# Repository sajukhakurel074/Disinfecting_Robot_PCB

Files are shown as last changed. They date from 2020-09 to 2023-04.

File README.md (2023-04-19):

# Disinfecting_Robot
Main circuit board design for disinfecting Robot Project.

This project was funded by Nepal Academy of Science and Technology (NAST) during the Covid-19 pandemic. The main aim of this project was to use a remotely comtrolled robot that would spary the disinfecting solution in the infected areas.

# Features of the board
1. Simple 4 wheel drive
2. Bluetooth controlled functions
3. Relay switched Water Pump
4. 2-D axis spraying arm 
  - Servo for y-axis
  - Stepper for x-axis
5. Proximity sensor at the edges to avoid collision

# Final Board After Assmebly 
119986601_873003923236254_8257088440001949787_n
119949055_959485604533560_8313327878339021860_n

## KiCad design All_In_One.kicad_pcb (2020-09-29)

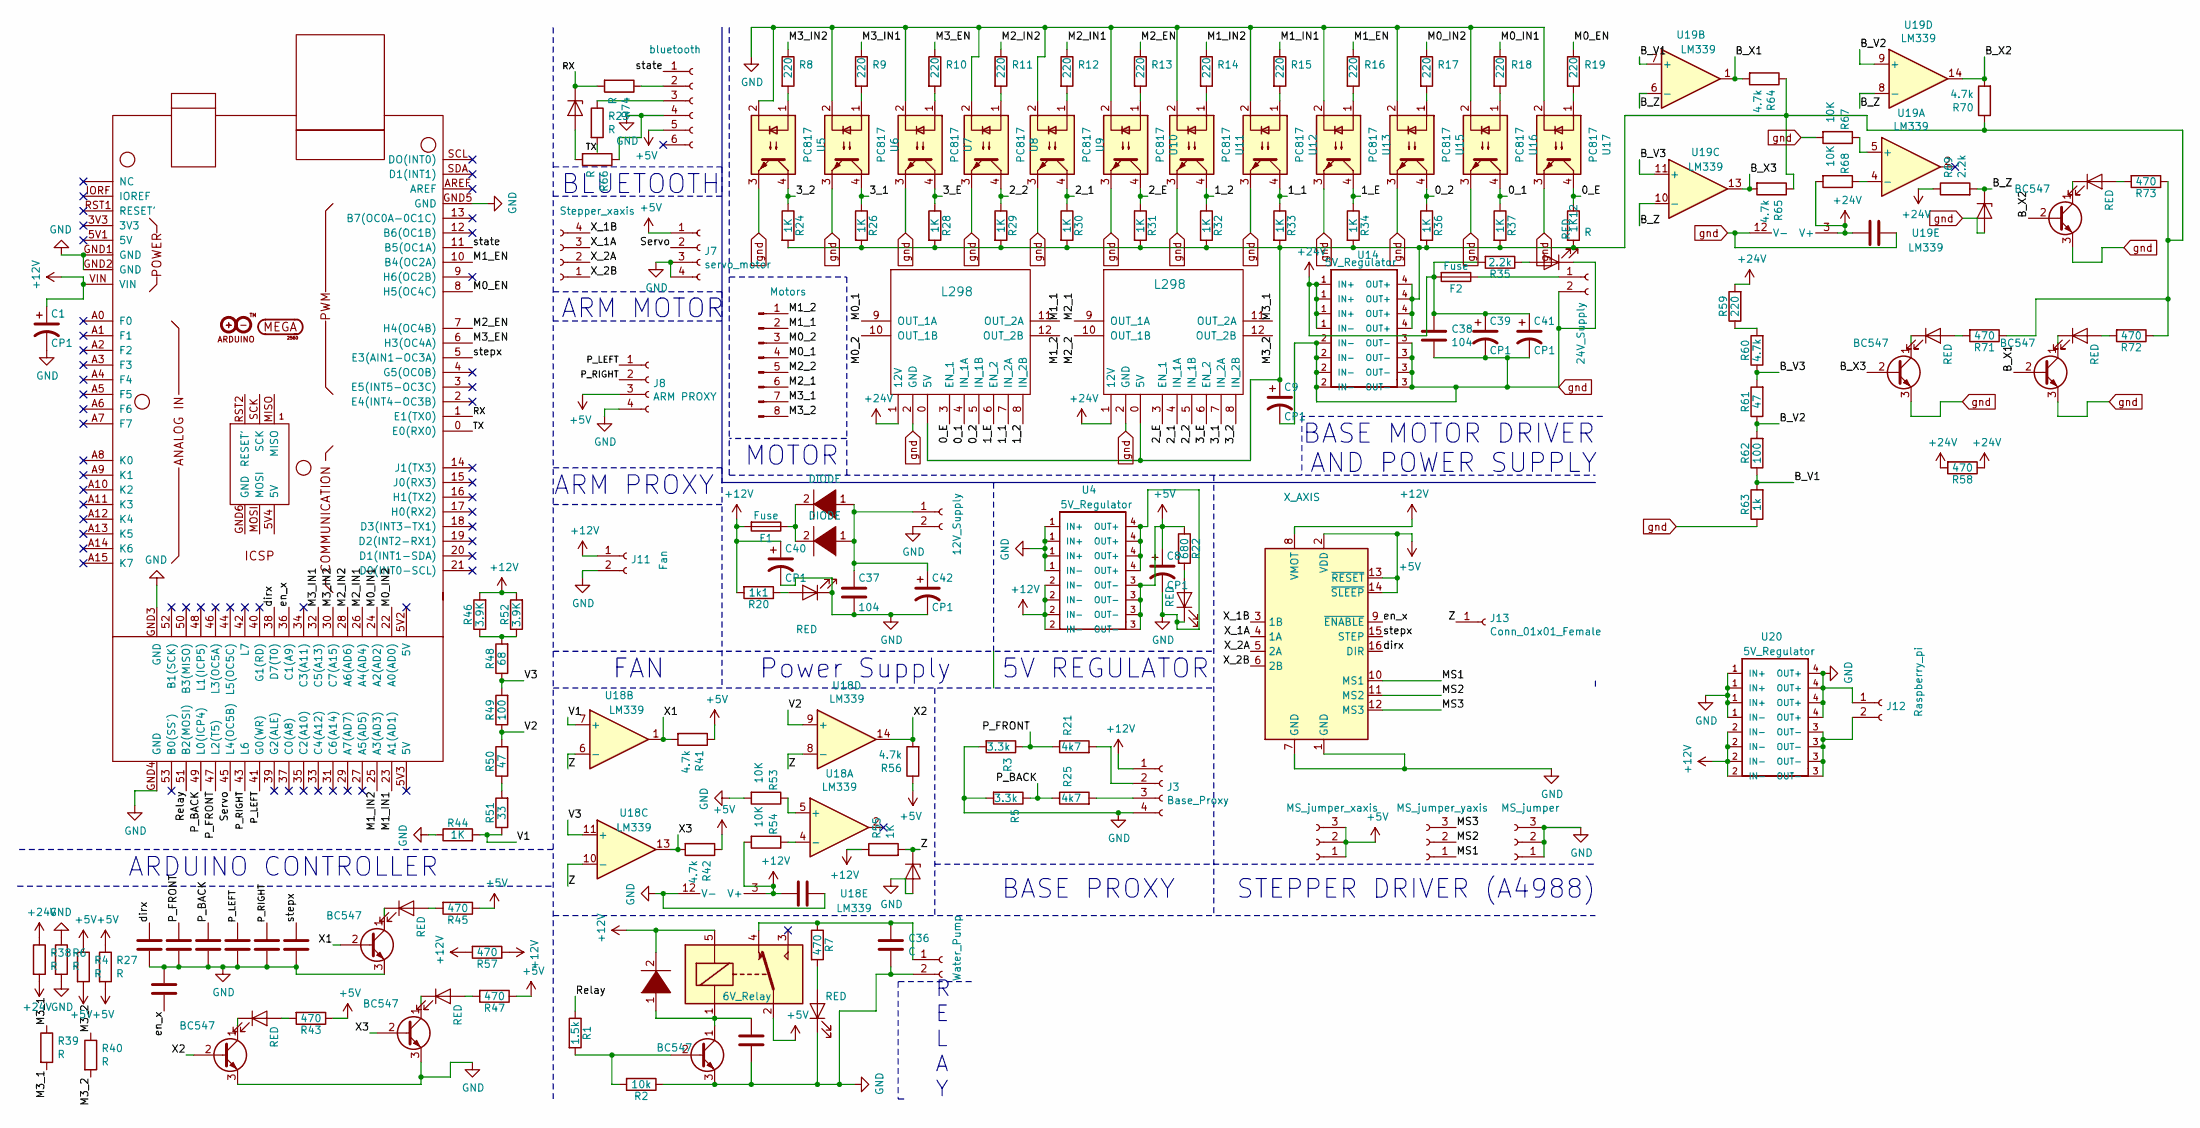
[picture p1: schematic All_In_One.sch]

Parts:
1K12: R; Resistor_small
A1: X_AXIS; A4998
C1, C8, C9, C40, C41: CP1; Capacitor_1000uF
C2, C3, C4, C5, C6, C7, C13, C25, C27, C33, C36: C; Capacitor_Disc_Small
C37, C38: 104; Capacitor_Disc_Small
C39, C42: CP1; Capacitor_10uF
D1, D3, D10: DIODE; Diode_Medium
D2, D4, D5, D6, D8, D9, D11, D13, D15, D16: RED; LED_D3.0mm
D7, D12, D14: D_Zener; D_T-1_P5.08mm_Horizontal
F1, F2: Fuse; Fuse_Holder
J1: MS_jumper_xaxis; PinHeader_1x03_P2.54mm_Vertical
J2: MS_jumper_yaxis; PinHeader_1x03_P2.54mm_Vertical
J3: Base_Proxy; New_conn_1x4
J4: Water_Pump; New_conn_1x2
J5: MS_jumper; PinHeader_1x03_P2.54mm_Vertical
J6: Stepper_xaxis; New_conn_1x4
J7: servo_motor; New_conn_1x4
J8: ARM PROXY; New_conn_1x4
J9: bluetooth
J10: Motors; New_conn_1x8
J11: Fan; New_conn_1x2
J12: Raspberry_pi; New_conn_1x2
J13: Conn_01x01_Female; PinHeader_1x01_P2.00mm_Vertical
Q1, Q2, Q3, Q4, Q5, Q6, Q7: BC547
R1: 1.5k; Resistor_small
R2: 10k; Resistor_small
R3, R5: 3.3k; Resistor_small
R4, R6, R23, R27, R38, R39, R40, R66, R74: R; Resistor_small
R7, R43, R45, R47, R57, R58, R71, R72, R73: 470; Resistor_small
R8, R9, R10, R11, R12, R13, R14, R15, R16, R17, R18, R19, R59: 220; Resistor_small
R20: 1k1; Resistor_small
R21, R25: 4k7; Resistor_small
R22: 680; Resistor_small
R24, R26, R28, R29, R30, R31, R32, R33, R34, R36, R37, R44, R55: 1K; Resistor_small
R35, R69: 2.2k; Resistor_small
R41, R42, R56, R60, R64, R65, R70: 4.7k; Resistor_small
R46, R52: 3.9K; Resistor_small
R48: 68; Resistor_small
R49, R62: 100; Resistor_small
R50, R61: 47; Resistor_small
R51: 33; Resistor_small
R53, R54, R67, R68: 10K; Resistor_small
R63: 1k; Resistor_small
Rly1: 6V_Relay; Relay_6V
U1: Prashant_library_Arduino_Mega2560_Shield; Arduino_Mega2560_Shield
U2, U3: L298; saju_____L298
U4, U20: 5V_Regulator; Buck_5A
U5, U6, U7, U8, U9, U10, U11, U12, U13, U15, U16, U17: PC817; DIP-4_W7.62mm
U14: 5V_Regulator; Buck_Regulator
U18, U19: LM339; DIP-14_W7.62mm_LongPads
d1: 12V_Supply; Solar_Connector
d2: 24V_Supply; Solar_Connector

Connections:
+5V: A1.2 (VDD), A1.13 (~RESET), A1.14 (~SLEEP), C8.1, J1.1, J1.2, J1.3, J7.1, J8.3, J9.5, R4.1, R4.2, R22.1, R27.1, R27.2, R41.1, R42.1, R43.1, R45.1, R47.1, R56.1, Rly1.2, U4.3 (OUT-); also elsewhere on the board
+12V: A1.8 (VMOT), C1.1, C4.2, C40.1, D1.2 (A), F1.2, J3.1, J11.1, R20.2, R46.2, R52.2, R54.2, R55.1, R57.1, R57.2, Rly1.5, U1.VIN, U4.2 (IN-), U18.3 (V+), U20.2 (IN-); also elsewhere on the board
+24V: C6.2, C38.1, C39.1, C41.1, F2.2, R35.2, R38.1, R38.2, R58.1, R58.2, R59.2, R68.2, R69.1, U2.1 (12V), U3.1 (12V), U14.1 (IN+), U19.3 (V+)
/0_1: R37.1, U2.4 (IN_1A), U16.4
/0_2: R36.1, U2.5 (IN_1B), U15.4
/0_E: 1K12.1, U2.3 (EN_1), U17.4
/1_1: R33.1, U2.7 (IN_2A), U12.4
/1_2: R32.1, U2.8 (IN_2B), U11.4
/1_E: R34.1, U2.6 (EN_2), U13.4
/2_1: R30.1, U3.4 (IN_1A), U9.4
/2_2: R29.1, U3.5 (IN_1B), U8.4
/2_E: R31.1, U3.3 (EN_1), U10.4
/3_1: R26.1, U3.7 (IN_2A), U6.4
/3_2: R24.1, U3.8 (IN_2B), U5.4
/3_E: R28.1, U3.6 (EN_2), U7.4
/B_V1: R62.1, R63.2, U19.7 (+)
/B_V2: R61.1, R62.2, U19.9 (+)
/B_V3: R60.1, R61.2, U19.11 (+)
/B_X1: Q6.2 (B), R64.2, U19.1
/B_X2: Q7.2 (B), R70.2, U19.14; also elsewhere on the board
/B_X3: Q5.2 (B), R65.2, U19.13
/B_Z: D14.1 (K), R69.2, U19.6 (-), U19.8 (-), U19.10 (-)
/M0_1: J10.4, U2.9 (OUT_1A)
/M0_2: J10.3, U2.10 (OUT_1B)
/M0_EN: R19.1, U1.8 (H5(OC4C))
/M0_IN1: R18.1, U1.24 (A2(AD2))
/M0_IN2: R17.1, U1.22 (A0(AD0))
/M1_1: J10.2, U2.11 (OUT_2A)
/M1_2: J10.1, U2.12 (OUT_2B)
/M1_EN: R16.1, U1.10 (B4(OC2A))
/M1_IN1: R15.1, U1.23 (A1(AD1))
/M1_IN2: R14.1, U1.25 (A3(AD3))
/M2_1: J10.6, U3.9 (OUT_1A)
/M2_2: J10.5, U3.10 (OUT_1B)
/M2_EN: R13.1, U1.7 (H4(OC4B))
/M2_IN1: R12.1, U1.26 (A4(AD4))
/M2_IN2: R11.1, U1.28 (A6(AD6))
/M3_1: J10.7, R39.1, R39.2, U3.11 (OUT_2A)
/M3_2: J10.8, R40.1, R40.2, U3.12 (OUT_2B)
/M3_EN: R10.1, U1.6 (H3(OC4A))
/M3_IN1: R9.1, U1.32 (C5(A13))
/M3_IN2: R8.1, U1.30 (C7(A15))
/MS1: A1.10 (MS1), J2.1; also elsewhere on the board
/MS2: A1.11 (MS2), J2.2; also elsewhere on the board
/MS3: A1.12 (MS3), J2.3; also elsewhere on the board
/P_BACK: C5.1, R5.1, R25.1, U1.49 (L0(ICP4))
/P_FRONT: C2.1, R3.1, R21.1, U1.47 (L2(T5))
/P_LEFT: C25.1, J8.1, U1.41 (G0(WR))
/P_RIGHT: C27.1, J8.2, U1.43 (L6)
/RX: D7.1 (K), R74.2, U1.1 (E1(TX0))
/Relay: R1.1, U1.51 (B2(MOSI))
/Servo: J7.2, U1.45 (L4(OC5B))
/TX: R23.2, U1.0 (E0(RX0))
/V1: R44.2, R51.1, U18.7 (+)
/V2: R49.1, R50.2, U18.9 (+)
/V3: R48.1, R49.2, U18.11 (+)
/X1: Q3.2 (B), R41.2, U18.1
/X2: Q2.2 (B), R56.2, U18.14
/X3: Q4.2 (B), R42.2, U18.13
/X_1A: A1.4 (1A), J6.3
/X_1B: A1.3 (1B), J6.4
/X_2A: A1.5 (2A), J6.2
/X_2B: A1.6 (2B), J6.1
/Z: D12.1 (K), J13.1, R55.2, U18.6 (-), U18.8 (-), U18.10 (-); also elsewhere on the board
/dirx: A1.16 (DIR), C13.1, U1.38 (D7(T0))
/en_x: A1.9 (~ENABLE), C3.1, U1.36 (C1(A9))
/state: J9.1, U1.11 (B5(OC1A))
/stepx: A1.15 (STEP), C33.1, U1.5 (E3(AIN1-OC3A))
GND: A1.1 (GND), A1.7 (GND), C1.2, C2.2, C3.2, C4.1, C5.2, C7.2, C8.2, C13.2, C25.2, C27.2, C33.2, C36.2, C37.2, C40.2, C42.2, D2.1 (K), D9.1 (K), D11.1 (K), D12.2 (A), J3.4, J4.2, J5.1, J5.2, J5.3, J7.3, J7.4, J8.4, J9.4, J11.2, J12.1, Q1.3 (E), Q2.3 (E), Q3.3 (E), Q4.3 (E), R2.1, R3.2, R5.2, R6.1, R6.2, R44.1, R53.2, R66.1, U1.GND1 (GND), U1.GND2 (GND), U1.GND3 (GND), U1.GND4 (GND), U1.GND5 (GND), U4.1 (IN+), U4.4 (OUT+), U5.2, U6.2, U7.2, U8.2, U9.2, U10.2, U11.2, U12.2, U13.2, U15.2, U16.2, U17.2, U18.12 (V-), U20.1 (IN+), U20.4 (OUT+), d1.2; also elsewhere on the board
unnamed 69: 1K12.2, C9.1, R24.2, R26.2, R28.2, R29.2, R30.2, R31.2, R32.2, R33.2, R34.2, R36.2, R37.2, R64.1, R65.1, R70.1, R71.1, R72.1, R73.1, U2.0 (5V), U3.0 (5V), U14.4 (OUT+); also elsewhere on the board
unnamed: C7.1, D1.1 (K), Q1.1 (C), Rly1.1
unnamed: C36.1, J4.1, R7.1, Rly1.4
unnamed 72: C37.1, C42.1, D3.1 (K), D10.1 (K), d1.1; also elsewhere on the board
unnamed: D2.2 (A), R7.2
unnamed: D4.1 (K), Q2.1 (C)
unnamed: D4.2 (A), R43.2
unnamed: D5.1 (K), Q3.1 (C)
unnamed: D5.2 (A), R45.2
unnamed: D6.1 (K), Q4.1 (C)
unnamed: D6.2 (A), R47.2
unnamed: D7.2 (A), R66.2
unnamed: D8.2 (A), R35.1
unnamed: D9.2 (A), R20.1
unnamed: D3.2 (A), D10.2 (A), F1.1
unnamed: D11.2 (A), R22.2
unnamed: D13.1 (K), Q5.1 (C)
unnamed: D13.2 (A), R71.2
unnamed: D15.1 (K), Q6.1 (C)
unnamed: D15.2 (A), R72.2
unnamed: D16.1 (K), Q7.1 (C)
unnamed: D16.2 (A), R73.2
unnamed: F2.1, d2.1
unnamed: J3.2, R21.2
unnamed: J3.3, R25.2
unnamed: J9.2, R74.1
unnamed: J9.3, R23.1
unnamed: J12.2, U20.3 (OUT-)
unnamed: Q1.2 (B), R1.2, R2.2
unnamed: R8.2, U5.1
unnamed: R9.2, U6.1
unnamed: R10.2, U7.1
unnamed: R11.2, U8.1
unnamed: R12.2, U9.1
unnamed: R13.2, U10.1
unnamed: R14.2, U11.1
unnamed: R15.2, U12.1
unnamed: R16.2, U13.1
unnamed: R17.2, U15.1
unnamed: R18.2, U16.1
unnamed: R19.2, U17.1
unnamed: R46.1, R48.2, R52.1
unnamed: R50.1, R51.2
unnamed: R53.1, U18.5 (+)
unnamed: R54.1, U18.4 (-)
unnamed: R59.1, R60.2
unnamed: R67.1, U19.5 (+)
unnamed: R68.1, U19.4 (-)
gnd: C6.1, C9.2, C38.2, C39.2, C41.2, D8.1 (K), D14.2 (A), Q5.3 (E), Q6.3 (E), Q7.3 (E), R63.1, R67.2, U2.2 (GND), U3.2 (GND), U5.3, U6.3, U7.3, U8.3, U9.3, U10.3, U11.3, U12.3, U13.3, U14.2 (IN-), U14.3 (OUT-), U15.3, U16.3, U17.3, U19.12 (V-), d2.2

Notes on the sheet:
ARM PROXY
5V REGULATOR
ARDUINO CONTROLLER
MOTOR
BASE PROXY
STEPPER DRIVER (A4988)
BASE MOTOR DRIVER
AND POWER SUPPLY
Power Supply
BLUETOOTH
R E L A Y
FAN
ARM MOTOR

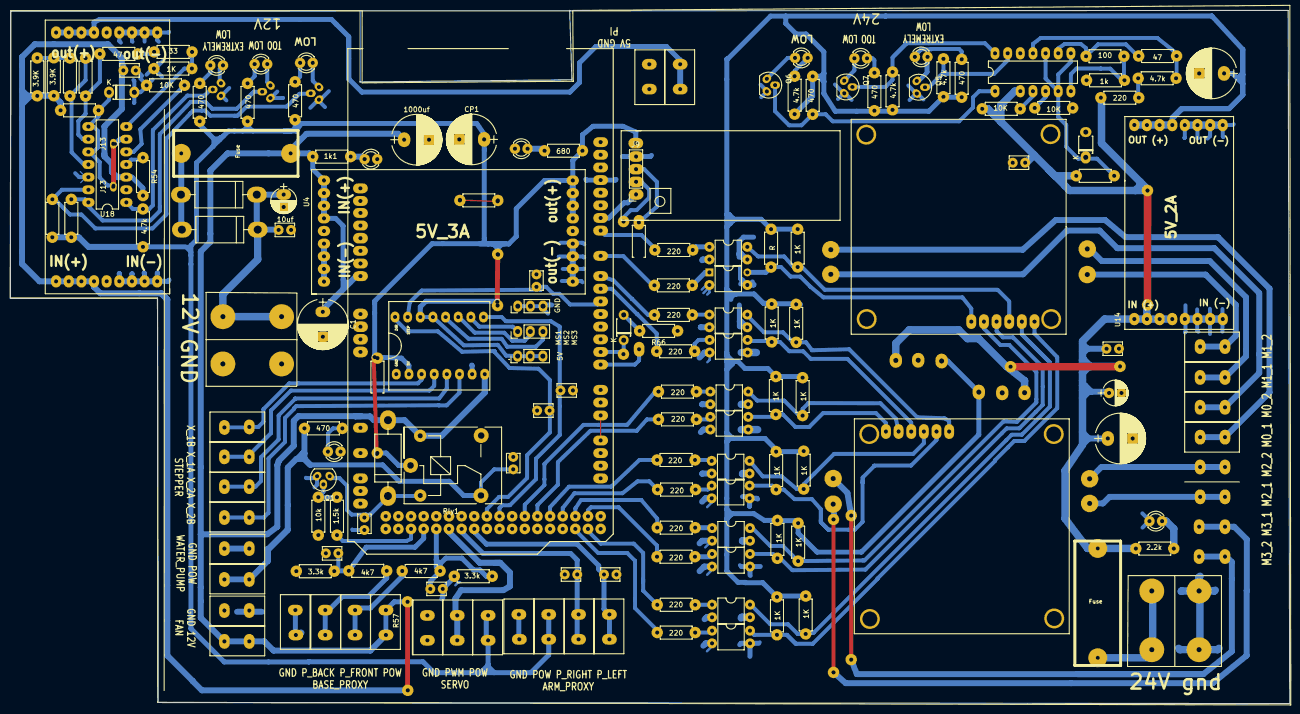
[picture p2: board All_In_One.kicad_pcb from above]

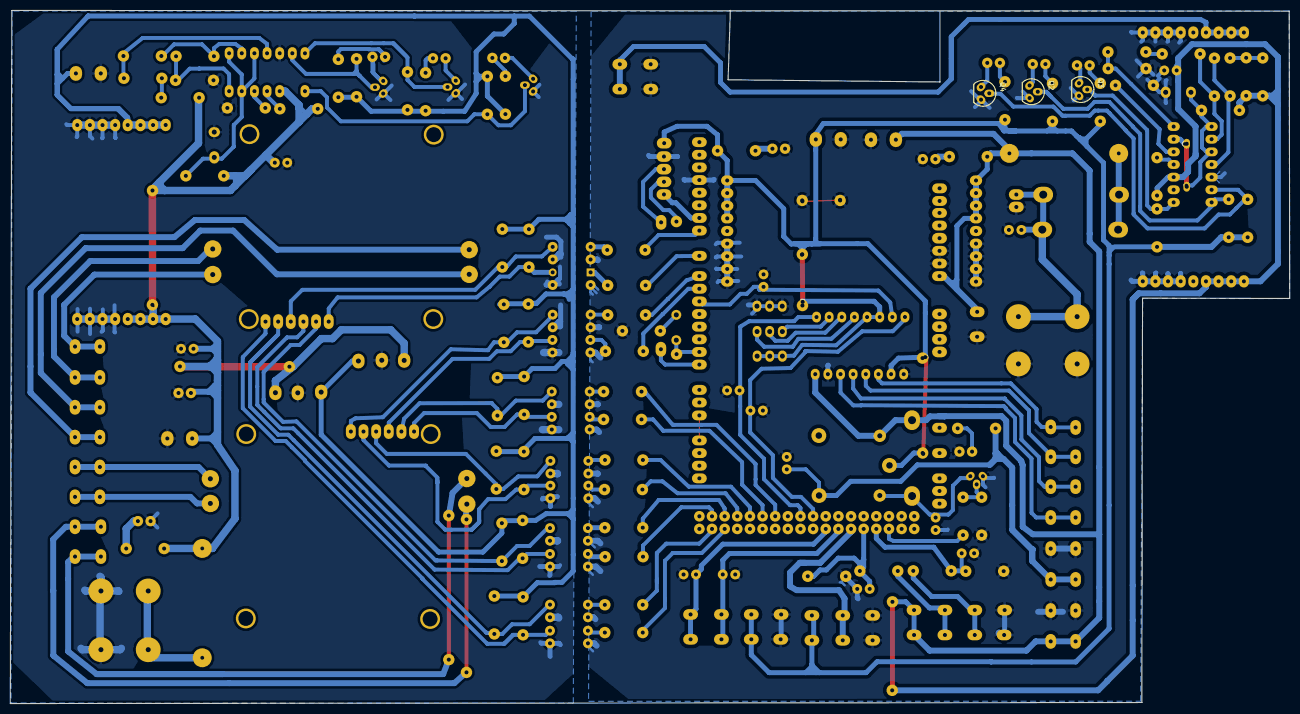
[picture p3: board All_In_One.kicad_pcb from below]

Board: 2 copper layers, 257.1 x 139.3 mm, 158 parts (3 on the bottom side), 118 nets.

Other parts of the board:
5V: MS_jumper_xaxis; PinHeader_1x03_P2.54mm_Vertical
10uf: CP1; Capacitor_10uF
1000uf: CP1; Capacitor_1000uF
GND: MS_jumper; PinHeader_1x03_P2.54mm_Vertical
J13#2: Conn_01x01_Female; PinHeader_1x01_P2.00mm_Vertical
MS1: MS_jumper_yaxis; PinHeader_1x03_P2.54mm_Vertical
eR70: 4.7k; Resistor_small

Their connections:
+5V: 5V.1, 5V.2, 5V.3; also elsewhere on the board
+12V: 1000uf.1; also elsewhere on the board
/B_X2: eR70.2; also elsewhere on the board
/MS1: MS1.1; also elsewhere on the board
/MS2: MS1.2; also elsewhere on the board
/MS3: MS1.3; also elsewhere on the board
/Z: J13#2.1; also elsewhere on the board
GND: 10uf.2, 1000uf.2, GND.1, GND.2, GND.3; also elsewhere on the board
unnamed 69: eR70.1; also elsewhere on the board
unnamed 72: 10uf.1; also elsewhere on the board

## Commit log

2020-08-05 complete schematic
    [All_In_One.sch]
2020-08-09 seperate ground for base motor and rest using opto-coupler
    [All_In_One.sch]
2020-08-14 started joining tracks
    [All_In_One.sch]
2020-08-15 completed joining tracks!
    [All_In_One.kicad_pcb, All_In_One.sch]
2020-08-16 completed circuit
    [All_In_One.kicad_pcb, All_In_One.sch]
2020-08-17 completed circuit1
    [All_In_One.kicad_pcb, All_In_One.sch]
2020-08-18 battery indicator
    [All_In_One.kicad_pcb, All_In_One.sch]
2020-08-18 added buck for pi
    [All_In_One.kicad_pcb, All_In_One.sch]
2020-08-20 completed board!
    [All_In_One.kicad_pcb, All_In_One.sch]
2020-09-29 finalized board
    [All_In_One.kicad_pcb, All_In_One.sch]
